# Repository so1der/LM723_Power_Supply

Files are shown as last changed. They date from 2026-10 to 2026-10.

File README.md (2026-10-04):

# LM723 Power Supply

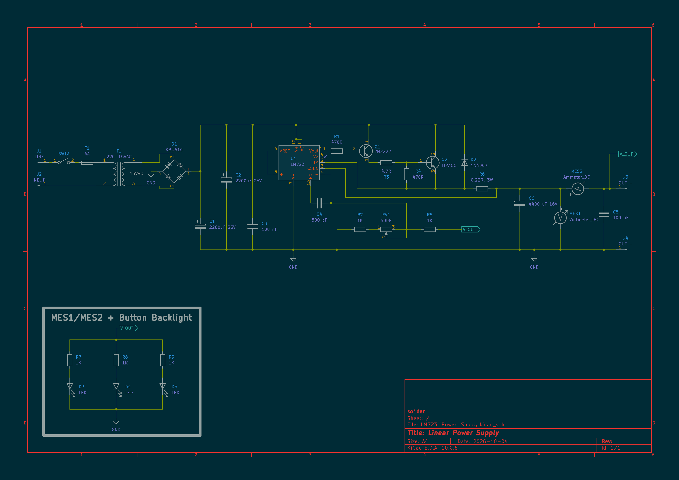
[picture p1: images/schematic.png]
"Schematic" Schematic


So this is a linear power supply based on the LM723 IC. It utilizes the LM723 chip and a TIP35C transistor for voltage regulation. The TIP35 transistor generates significant heat, so it requires effective cooling — specifically a heatsink and ideally a fan, though a large heatsink alone may suffice.

Resistor RV1 is used to adjust the output voltage.

The current limiter engages when the output current exceeds by approximately 3A.

An N11BW enclosure was used for the power supply - custom front and rear panels were designed for it, and the corresponding stl files are available in the repository.

---

Перед вами - лінійний блок живлення на мікросхемі LM723. Він використовує мікросхему LM723 та транзистор TIP35C для стабілізації напруги. Транзистор TIP35 буде доволі сильно грітись, тому він потребує гарне охолодження - радіатор, та в ідеалі вентилятор, але можна обійтись і просто великим радіатором.

Резистор RV1 використовується для підлаштування вихідної напруги.

Після приблизно 3А струму на виході - спрацьовує обмежувач струму.

В якості корпусу для блоку живлення був використаний корпус N11BW, для якого були спроєктовані передня та задня панелі - їх stl файли також знаходяться в репозиторії.

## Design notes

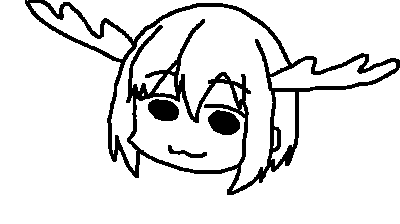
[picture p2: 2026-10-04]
LM723-Power-Supply/shika.png

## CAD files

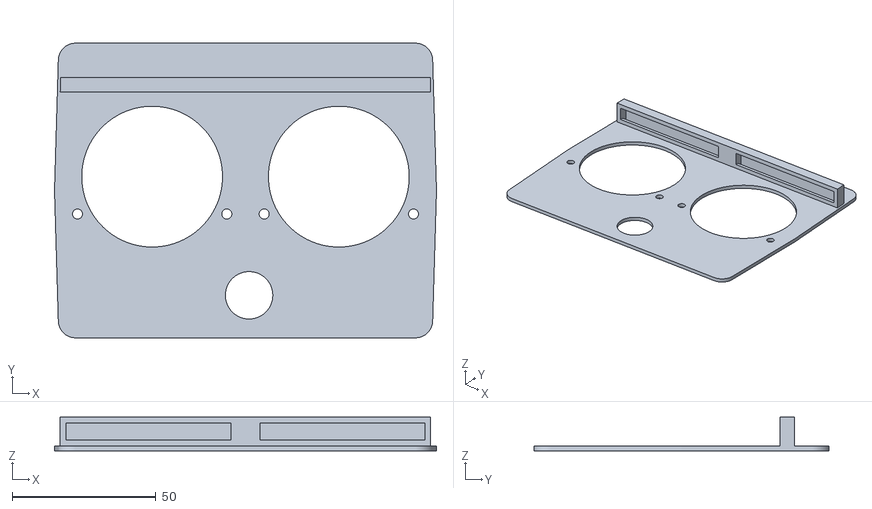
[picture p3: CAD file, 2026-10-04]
N11BW/linear_power_supply-front_panel.stl
133.0 x 102.6 x 11.7

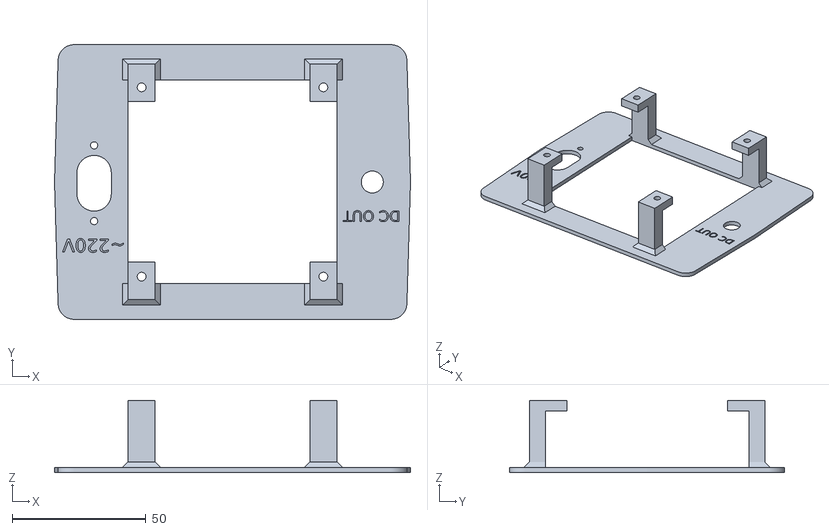
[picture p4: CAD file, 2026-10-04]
N11BW/linear_power_supply-back_panel.stl
133.0 x 102.6 x 27.0

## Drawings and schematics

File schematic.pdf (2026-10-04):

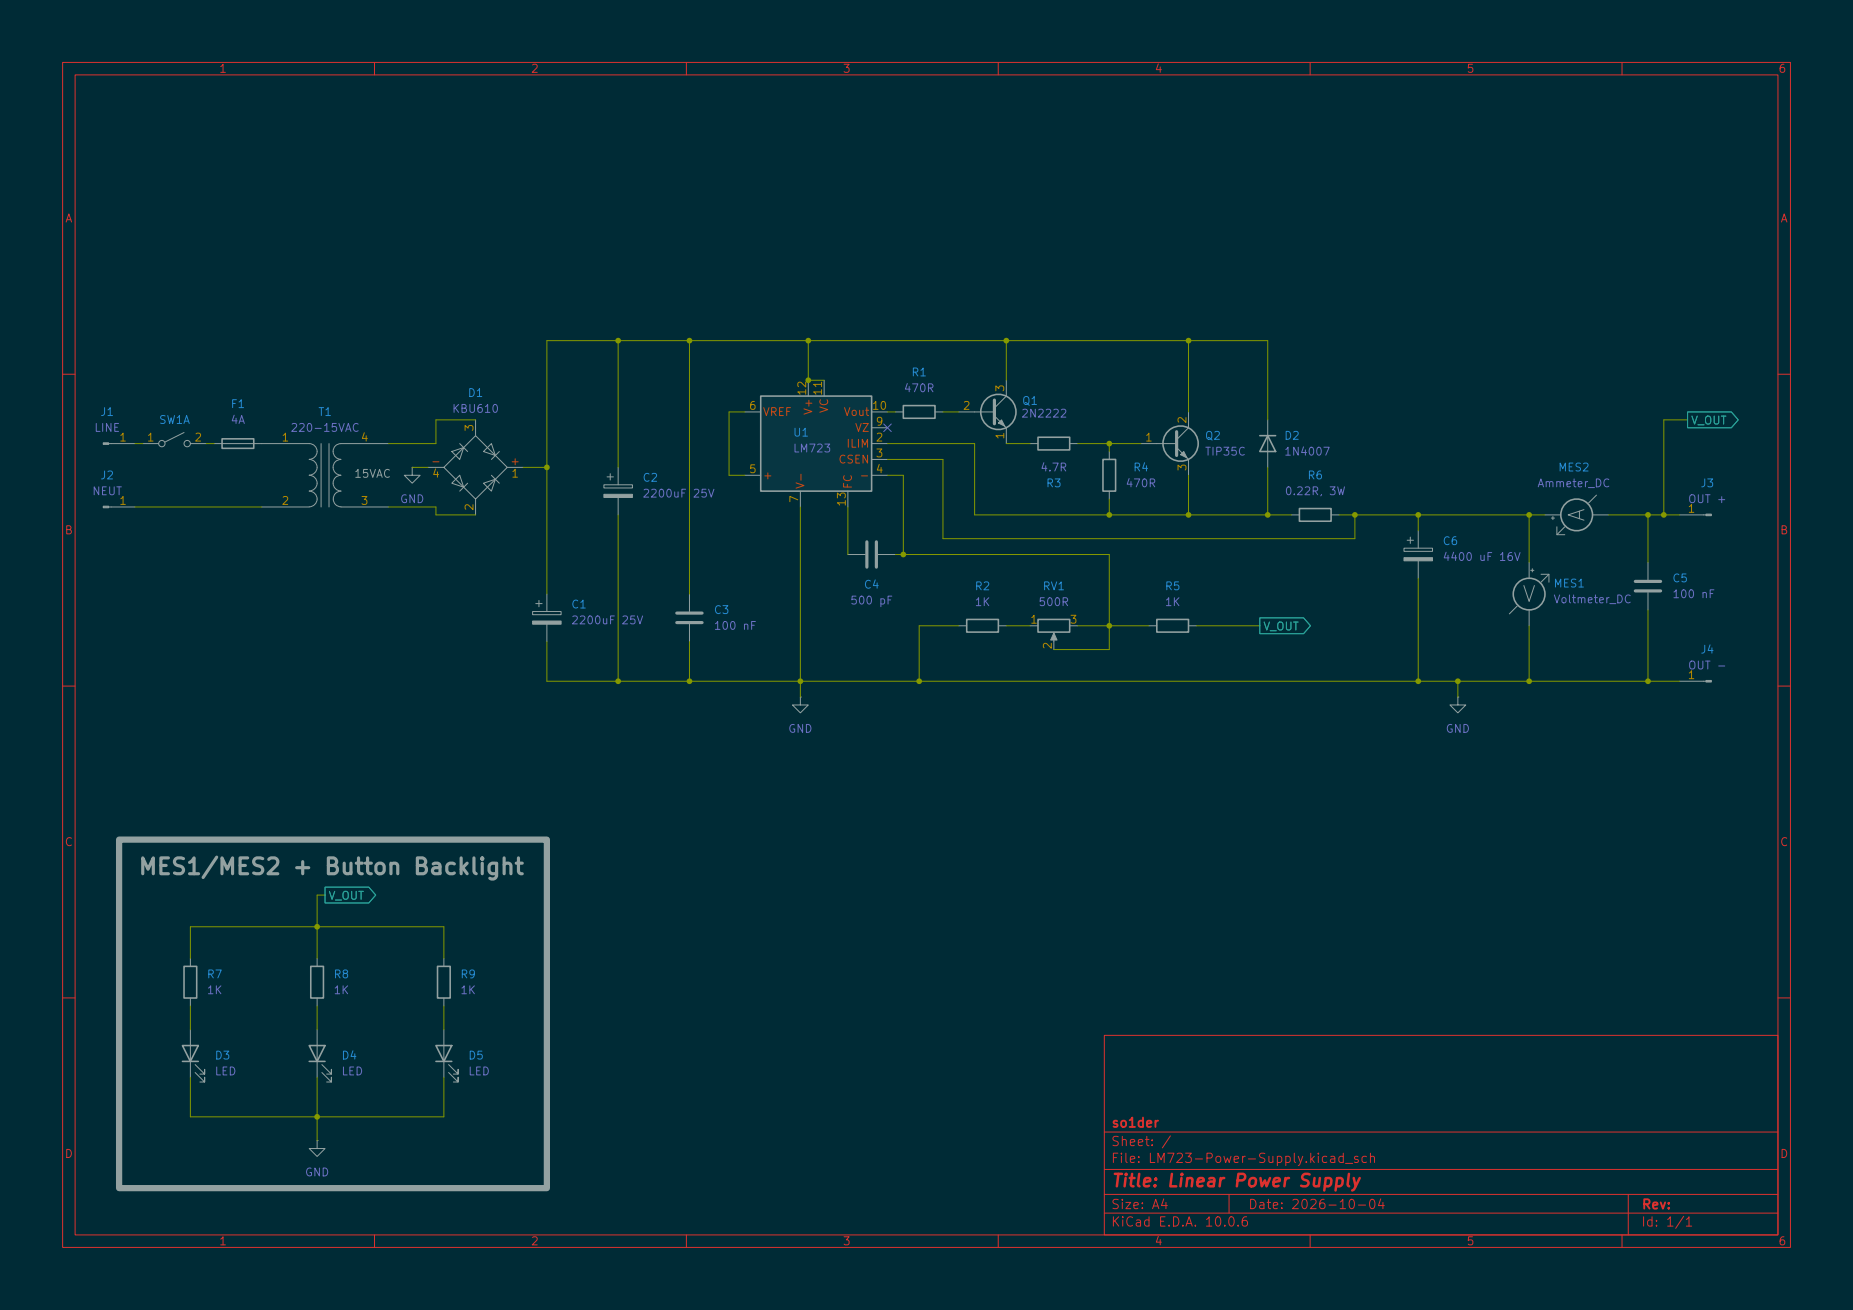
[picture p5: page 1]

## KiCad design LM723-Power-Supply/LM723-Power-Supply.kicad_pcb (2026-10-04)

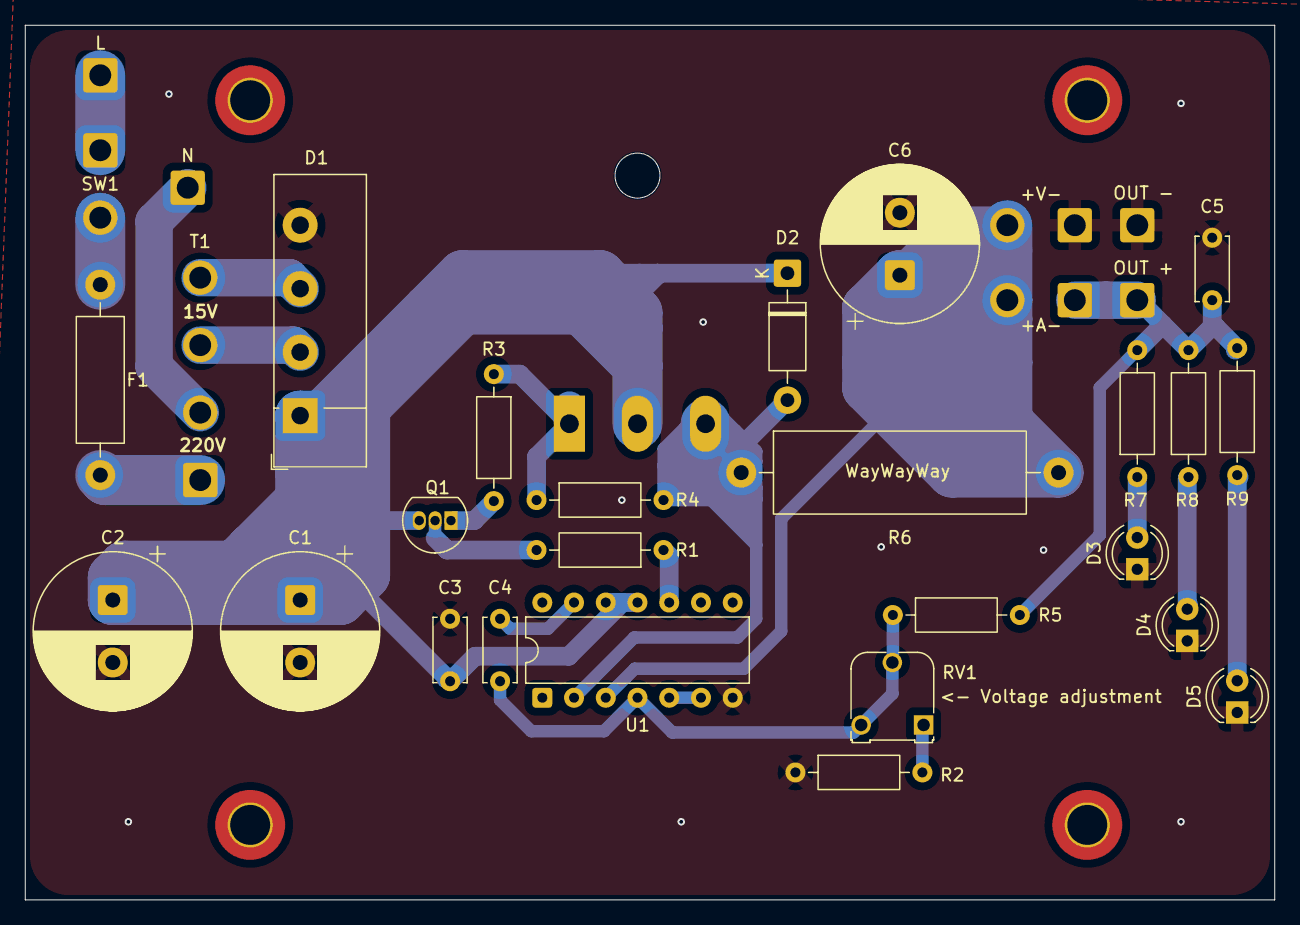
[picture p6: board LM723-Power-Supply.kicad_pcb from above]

Board: 2 copper layers, 100.0 x 70.0 mm, 33 parts (1 on the bottom side), 22 nets.

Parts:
+A-: Ammeter_DC; SolderWire-1sqmm_1x02_P5.4mm_D1.4mm_OD2.7mm
+V-: Voltmeter_DC; SolderWire-1sqmm_1x02_P5.4mm_D1.4mm_OD2.7mm
C1, C2: 2200uF 25V; CP_Radial_D12.5mm_P5.00mm
C3, C5: 100 nF; C_Disc_D5.0mm_W2.5mm_P5.00mm
C4: 500 pF; C_Disc_D5.0mm_W2.5mm_P5.00mm
C6: 1000uF 25V; CP_Radial_D12.5mm_P5.00mm
D1: KBU610; Diode_Bridge_Vishay_KBU
D2: 1N4007; D_DO-41_SOD81_P10.16mm_Horizontal
D3, D4, D5: LED; LED_D4.0mm
F1: 500 mA; R_Axial_DIN0411_L9.9mm_D3.6mm_P15.24mm_Horizontal
L: LINE; SolderWire-1sqmm_1x01_D1.4mm_OD2.7mm
N: NEUT; SolderWire-1sqmm_1x01_D1.4mm_OD2.7mm
OUT +: OUT +; SolderWire-1sqmm_1x01_D1.4mm_OD2.7mm
OUT -: OUT -; SolderWire-1sqmm_1x01_D1.4mm_OD2.7mm
Q1: 2N2222; TO-92_Inline
Q2: TIP35C; TO-247-3_Horizontal_TabUp
R1, R4: 470R; R_Axial_DIN0207_L6.3mm_D2.5mm_P10.16mm_Horizontal
R2, R5, R7, R8, R9: 1K; R_Axial_DIN0207_L6.3mm_D2.5mm_P10.16mm_Horizontal
R3: 47R; R_Axial_DIN0207_L6.3mm_D2.5mm_P10.16mm_Horizontal
R6: 0.22R, 3W; R_Axial_Power_L20.0mm_W6.4mm_P25.40mm
RV1: 200R; Potentiometer_Runtron_RM-065_Vertical
SW1: SW_DPST_x2; SolderWire-1sqmm_1x02_P5.4mm_D1.4mm_OD2.7mm
T1: 220-15VAC; SolderWire-1sqmm_1x04_P5.4mm_D1.4mm_OD2.7mm
U1: LM723; DIP-14_W7.62mm

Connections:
GND: +V-.1 (-), C1.2, C2.2, C3.2, C5.2, C6.2, D1.4 (-), D3.1 (K), D4.1 (K), D5.1 (K), OUT -.1 (Pin_1_1), R2.1, U1.7 (V-)
unnamed: C1.1, C2.1, C3.1, D1.1 (+), D2.1 (K), Q1.3 (C), Q2.2 (C), U1.11 (VC), U1.12 (V+)
unnamed: D2.2 (A), Q2.3 (E), R4.2, R6.1, U1.2 (ILIM)
unnamed: D3.2 (A), R7.1
unnamed: D4.2 (A), R8.1
unnamed: D5.2 (A), R9.2
unnamed: L.1 (Pin_1_1), SW1.1 (A)
unnamed: N.1 (Pin_1_1), T1.2 (AB)
unnamed: +A-.2 (+), +V-.2 (+), C6.1, R6.2, U1.3 (CSEN)
unnamed: Q1.2 (B), R1.2
unnamed: Q1.1 (E), R3.2
unnamed: Q2.1 (B), R3.1, R4.1
unnamed: R2.2, RV1.1
unnamed: F1.1, SW1.2 (B)
unnamed: F1.2, T1.1 (AA)
unnamed: D1.2, T1.3 (SA)
unnamed: D1.3, T1.4 (SB)
unnamed: U1.5 (+), U1.6 (VREF)
unnamed: C4.1, R5.1, RV1.2, RV1.3, U1.4 (-)
unnamed: C4.2, U1.13 (FC)
unnamed: R1.1, U1.10 (Vout)
V_OUT: +A-.1 (-), C5.1, OUT +.1 (Pin_1_1), R5.2, R7.2, R8.2, R9.1

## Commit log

2026-10-04 add schematic
2026-10-04 add kicad project
    [LM723-Power-Supply.kicad_pcb, LM723-Power-Supply.kicad_sch]
2026-10-04 add gerber files
2026-10-04 add stl files
    [linear_power_supply-back_panel.stl, linear_power_supply-front_panel.stl]
